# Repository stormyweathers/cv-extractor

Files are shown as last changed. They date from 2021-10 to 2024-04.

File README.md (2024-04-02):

# CV Extractor

This is an envelope detector eurorack module.
It is intended to take in eurorack signals or audio input and output the envelope.

## Description of schematic
An input waveform passes through an adjustable gain noninverting amplifier, then an active rectifier, then finally a 2-pole sallen-key LPF with adjustable gain and cutoff.

## Features

    * Buffered input/output
    * Adjustable input/output gain
    * Adjustable timescale of envelope detection

## Rack info

    * +12V: ?? mA
    * -12V: ?? mA
    *  +5V: unused
    * Width: 8HP   

## Issues

The module works, but its not that great.

    * Gain Pots are oriented reverse, unintuitive
    * Turning the cutoff knob can cause it to oscillate
    * The gain range is too large

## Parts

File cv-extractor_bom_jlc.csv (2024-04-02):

Comment | Designator | Footprint | LCSC Part #
470nF | C1,C5,C6 | C_0603_1608Metric | C1623
100uF | C7,C8 | CP_Elec_6.3x7.7 | C176675
1nF | C9,C10 | C_0603_1608Metric | C1588
D | D2,D1 | D_SOD-323F | C2128
1k | R7,R8,R5,R4,R6,R3,R2,R1,R12,R9 | R_0603_1608Metric | C21190
1M | RD1 | R_0603_1608Metric | C21190
TL074 | U1 | SOIC-14_3.9x8.7mm_P1.27mm | C12594

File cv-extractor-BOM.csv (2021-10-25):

Comment | Designator | Footprint | Quantity
100uF | C3,C1,C2,C4,C5,C6 | C_1206_3216Metric | 6
100uF | C7,C8 | CP_Elec_6.3x7.7 | 2
1nF | C9,C10 | C_0603_1608Metric | 2
D | D1,D2 | D_SMA | 2
1k | R1,R2,R3,R4,R5,R6,R7,R8 | R_0603_1608Metric | 8
TL074 | U1 | SOIC-14_3.9x8.7mm_P1.27mm | 1

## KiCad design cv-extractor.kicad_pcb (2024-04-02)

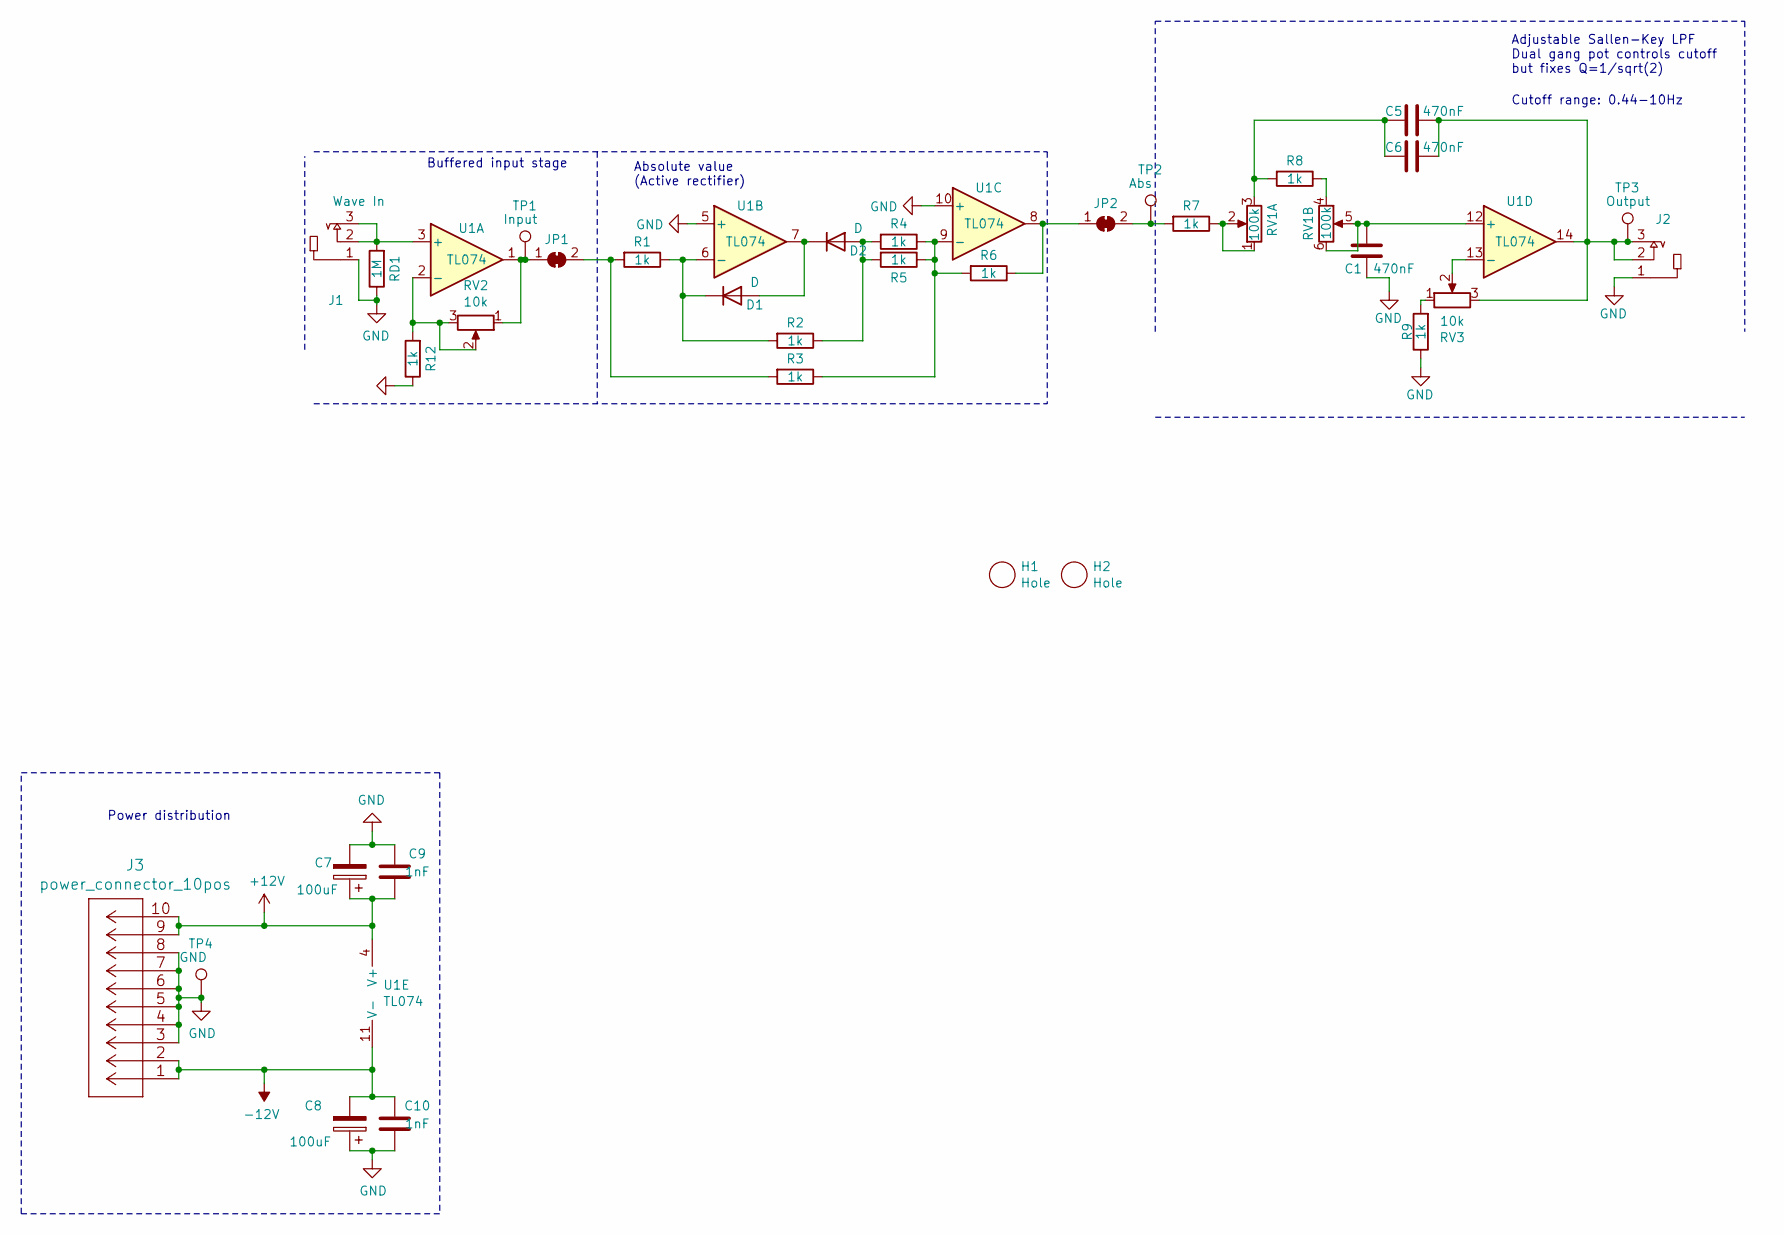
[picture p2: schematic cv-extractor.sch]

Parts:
C1, C5, C6: 470nF; C_0603_1608Metric; JLCPCB C1623
C7, C8: 100uF; CP_Elec_6.3x7.7; JLCPCB C176675
C9, C10: 1nF; C_0603_1608Metric; JLCPCB C1588
D1, D2: D; D_SOD-323F; JLCPCB C2128
H1, H2: Hole; MountingHole_3.2mm_M3
J1: Wave In; mono-jack-thonk
J2: CV Out; mono-jack-thonk
J3: power_connector_10pos; Digikey 732-2094-ND
JP1, JP2: SolderJumper_2_Bridged; SolderJumper-2_P1.3mm_Open_RoundedPad1.0x1.5mm
R1, R2, R3, R4, R5, R6, R7, R8, R9, R12: 1k; R_0603_1608Metric; JLCPCB C21190
RD1: 1M; R_0603_1608Metric; JLCPCB C21190
RV1: 100k; dual-pot-P120
RV2, RV3: 10k; pot_bourns_PTV09
TP1: Input; TestPoint_TP107
TP2: Abs; TestPoint_TP107
TP3: Output; TestPoint_TP107
TP4: GND; TestPoint_TP107
U1: TL074; SOIC-14_3.9x8.7mm_P1.27mm

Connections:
+12V: C7.1, C9.2, J3.9, J3.10, U1.4 (V+)
-12V: C8.2, C10.1, J3.1, J3.2, U1.11 (V-)
GND: C1.1, C7.2, C8.1, C9.1, C10.2, J1.1, J2.1, J3.3, J3.4, J3.5, J3.6, J3.7, J3.8, R9.1, R12.1, RD1.1, TP4.1, U1.5 (+), U1.10 (+)
unnamed: C1.2, RV1.5, RV1.6, U1.12 (+)
unnamed: C5.1, C6.1, R8.2, RV1.3
unnamed: C5.2, C6.2, J2.2, J2.3, RV3.3, TP3.1, U1.14
unnamed: D1.1 (K), R1.1, R2.2, U1.6 (-)
unnamed: D1.2 (A), D2.1 (K), U1.7
unnamed: D2.2 (A), R2.1, R4.2, R5.2
unnamed: J1.2, J1.3, RD1.2, U1.3 (+)
unnamed: JP1.1 (A), RV2.1, TP1.1, U1.1
unnamed: JP1.2 (B), R1.2, R3.2
unnamed: JP2.1 (A), R6.1, U1.8
unnamed: JP2.2 (B), R7.2, TP2.1
unnamed: R3.1, R4.1, R5.1, R6.2, U1.9 (-)
unnamed: R7.1, RV1.1, RV1.2
unnamed: R8.1, RV1.4
unnamed: R9.2, RV3.1
unnamed: R12.2, RV2.2, RV2.3, U1.2 (-)
unnamed: RV3.2, U1.13 (-)

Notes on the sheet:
Adjustable Sallen-Key LPF Dual gang pot controls cutoff but fixes Q=1/sqrt(2)
Buffered input stage
Power distribution
Absolute value (Active rectifier)
Cutoff range: 0.44-10Hz

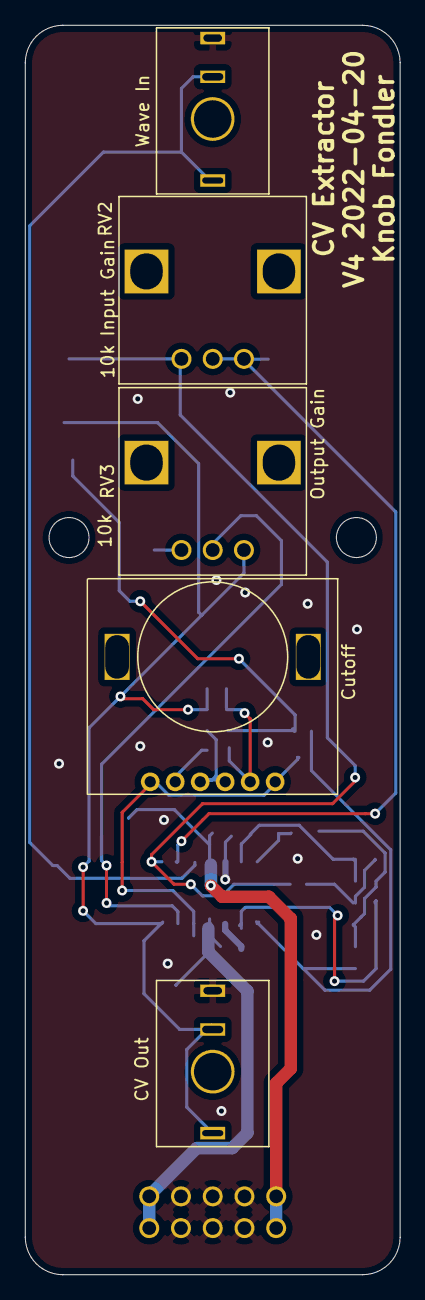
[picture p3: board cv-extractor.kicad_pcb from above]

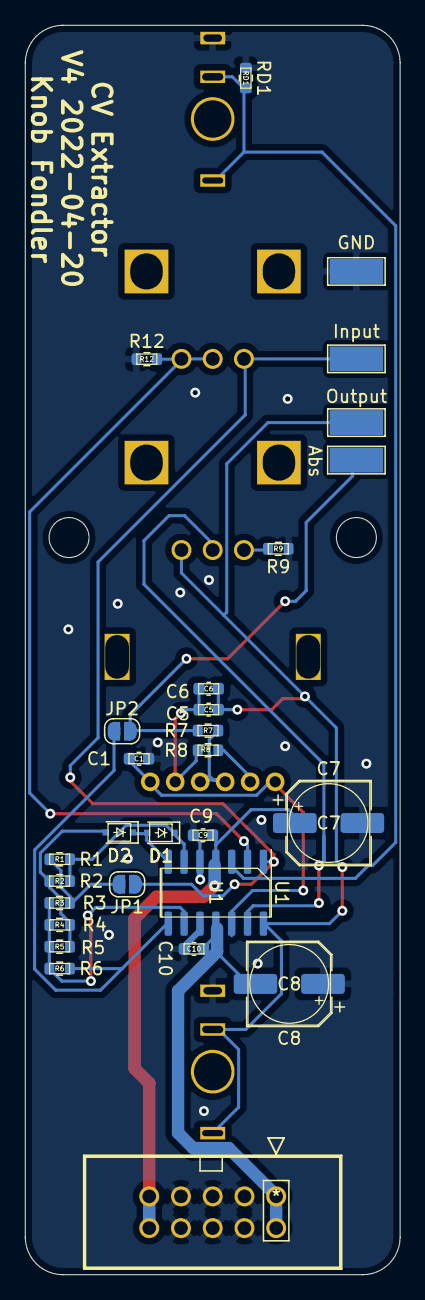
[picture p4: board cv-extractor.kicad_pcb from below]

Board: 2 copper layers, 30.0 x 100.0 mm, 35 parts (28 on the bottom side), 20 nets.

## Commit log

2021-10-25 init commit v1
    [cv-extractor-BOM.csv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]
2021-10-27 narrower profile, added test points, reduced cutoff range, V2 for fab
    [cv-extractor-B_Cu.gbr, cv-extractor-B_Mask.gbr, cv-extractor-B_Paste.gbr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]
2024-04-02 havent been good about commits, its at V4 now
    [cv-extractor-B_Cu.gbr, cv-extractor-B_Mask.gbr, cv-extractor-B_Paste.gbr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]

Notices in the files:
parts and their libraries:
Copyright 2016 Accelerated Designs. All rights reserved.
